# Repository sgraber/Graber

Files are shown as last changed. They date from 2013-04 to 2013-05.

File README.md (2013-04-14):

Graber i3 3D Printer
=================

This is the home of the Graber i3 3D printer: http://www.flickr.com/photos/sbgraber/8536293604/in/photostream/lightbox/

This printer design takes a lot of inspiration from Josef Prusa's awesome 
Prusa i3 printer:

http://reprap.org/wiki/Prusa_i3_Build_Manual#Single_Sheet_Frame_Style

I have decided to give it a name as the design is enough of a departure from its predecessor
that it needs differentiating. I am calling it the "Graber i3" 3D printer. Note on
pronunciation: the 'a' in 'Graber' is long.

What I have done is completely redesign the entire i3 concept to make it laser 
cuttable.  Some designs have taken this idea part-way, making the frame laser
cuttable along with certain motor mounts. With my design, there are no printed
parts, although one could print certain parts if need-be. 

The overall build envelope dimensions remain the same as the Prusa i3, which is
200mm x 200mm x 200mm.

A bill of materials is forthcoming. That said, it is really pretty straight-forward
once you have the laser cut frame put together. I have added some basic labeling
to each part to make assembly easier and here is the part rundown:

* Bottom (A) - 1
* Left Brace (B) - 1
* Right Brace (C) - 1
* Front (D) - 1
* Back (E) - 1
* Frame (F) - 1
* Z-Motor Mount Bottom (G) - 2
* Z-Motor Mount Bottom Brace (H) - 2
* Z-Top (I) - 2
* Z-Smooth Rod Constraint (J) - 2
* Y-Motor Mount (K) - 1
* Y-Idler (L) - 2
* Y-Carriage (M) - 1
* X-Carriage (N) - 2
* Y-Smooth Rod Stop (O) - 4
* Y-Belt Holder (P) - 2
* X-axis smooth rod spacer (Q) - 4
* X-Idler Front (R) - 1
* X-Idler Middle (S) - 1
* X-Idler Back (T) - 1
* X-Idler Top / Bottom (U) - 2
* X-Idler Cap (V) - 1
* X-Motor Front (W) - 1
* X-Motor Middle (X)- 1
* X-Motor Back (Y) - 1
* X-Motor Top / Bottom (Z) - 2
* X-Motor Cap (AA) - 1

NOTE: The long term goal is to make this 3D printer completely laser cuttable, minus the extruder.
Right now the x-motor and x-idler parts remain the only parts untested.  I have just 
committed an x-idler and x-motor that may work. If you choose to build this printer
before these parts are tested, you can use the standard Prusa i3 x-motor and x-idler
parts (even the x-carriage too if you want) and the printer will work fine. 
Expect regular changes to this repository
in the coming weeks, so don't get too comfortable if you download this to cut just
yet.  :)

If you find a bug, I welcome notifications, fixes, and even new contributions.

License
=======

This printer is released under the GNU GENERAL PUBLIC LICENSE v.3, same as its
predecessor.  See LICENSE.md for further details.

Usage
=====

Since this printer is released under the GNU GPL v.3, it is free for anyone to use,
reuse, sell, etc.  One thing I'd ask is if you do sell it that you 
financially contributing back to its continued development and maintenance. 
Contact me at sgraber@gmail.com if willing.

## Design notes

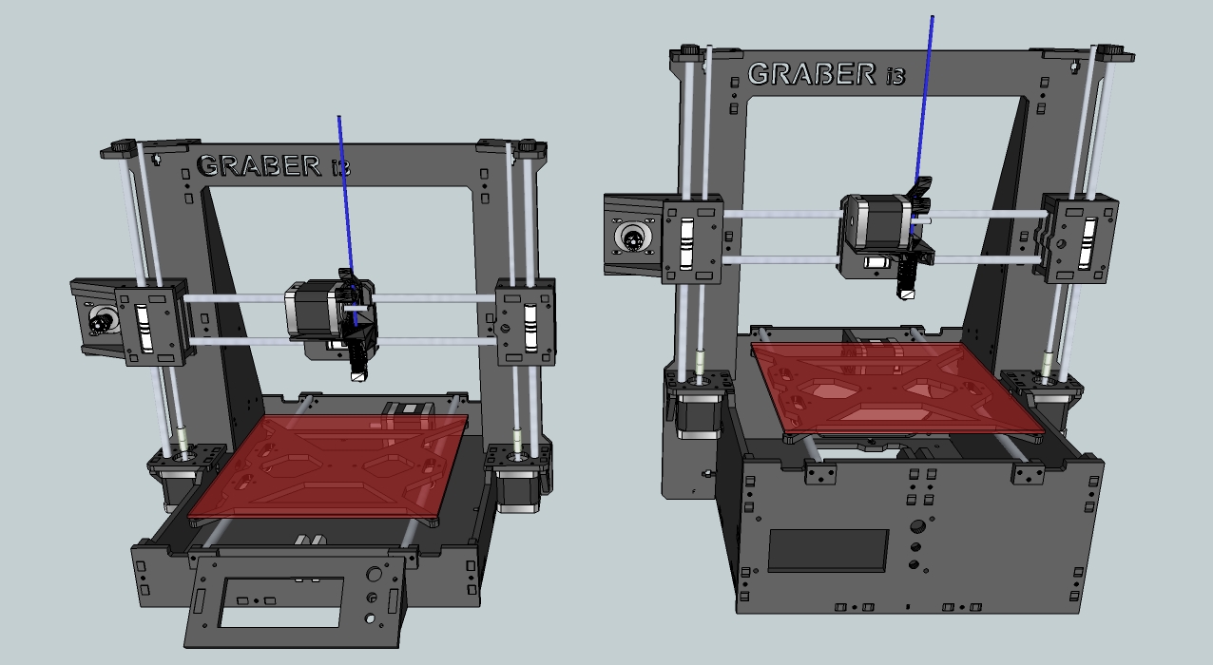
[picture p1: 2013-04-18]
graber-atx-3d2.jpg

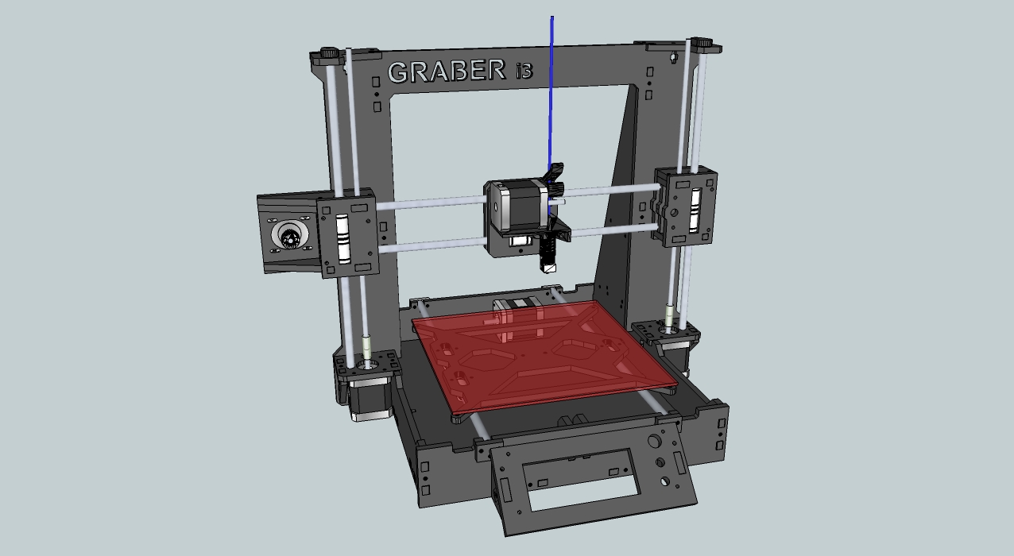
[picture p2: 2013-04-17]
graber-3d.jpg

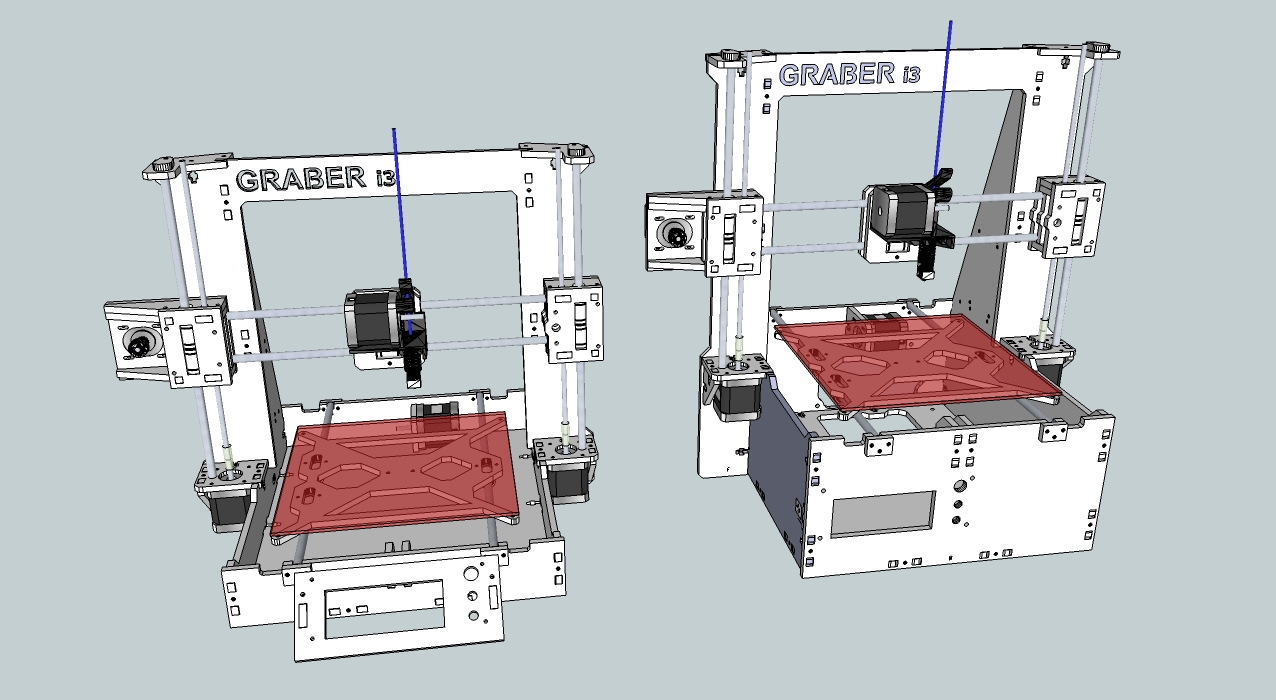
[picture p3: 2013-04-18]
graber-atx-3d.jpg

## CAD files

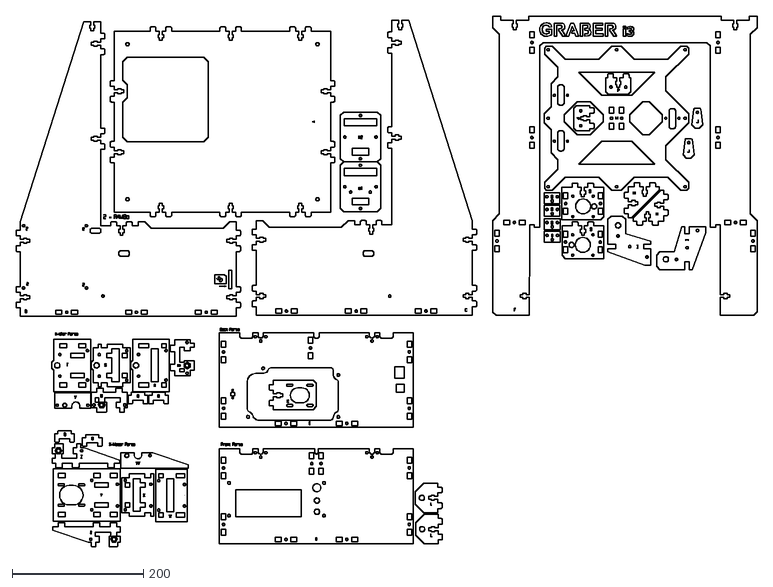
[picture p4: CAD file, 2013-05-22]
graber-atx.dxf
1130.7 x 809.1

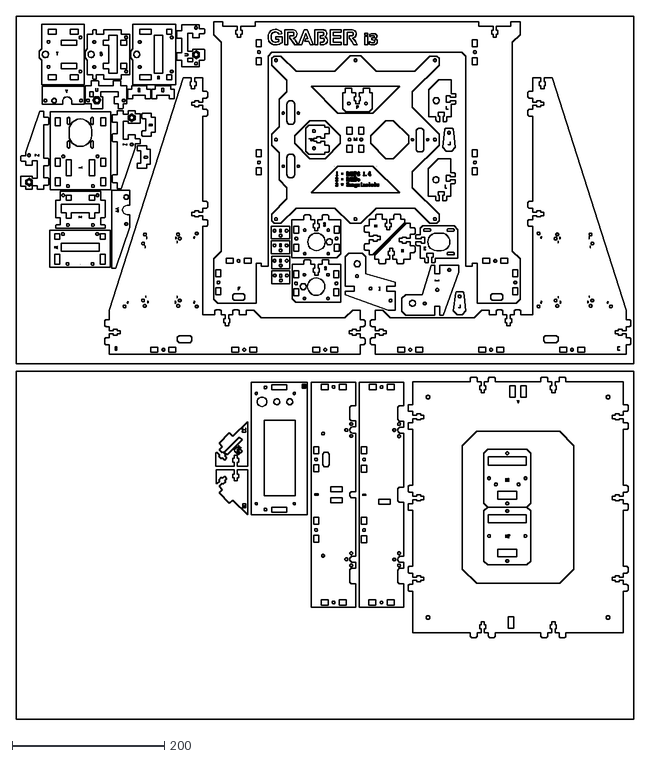
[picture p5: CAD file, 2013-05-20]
graber.dxf
812.8 x 924.7

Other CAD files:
graber-3d.skp
graber-atx.skp
graber.skp

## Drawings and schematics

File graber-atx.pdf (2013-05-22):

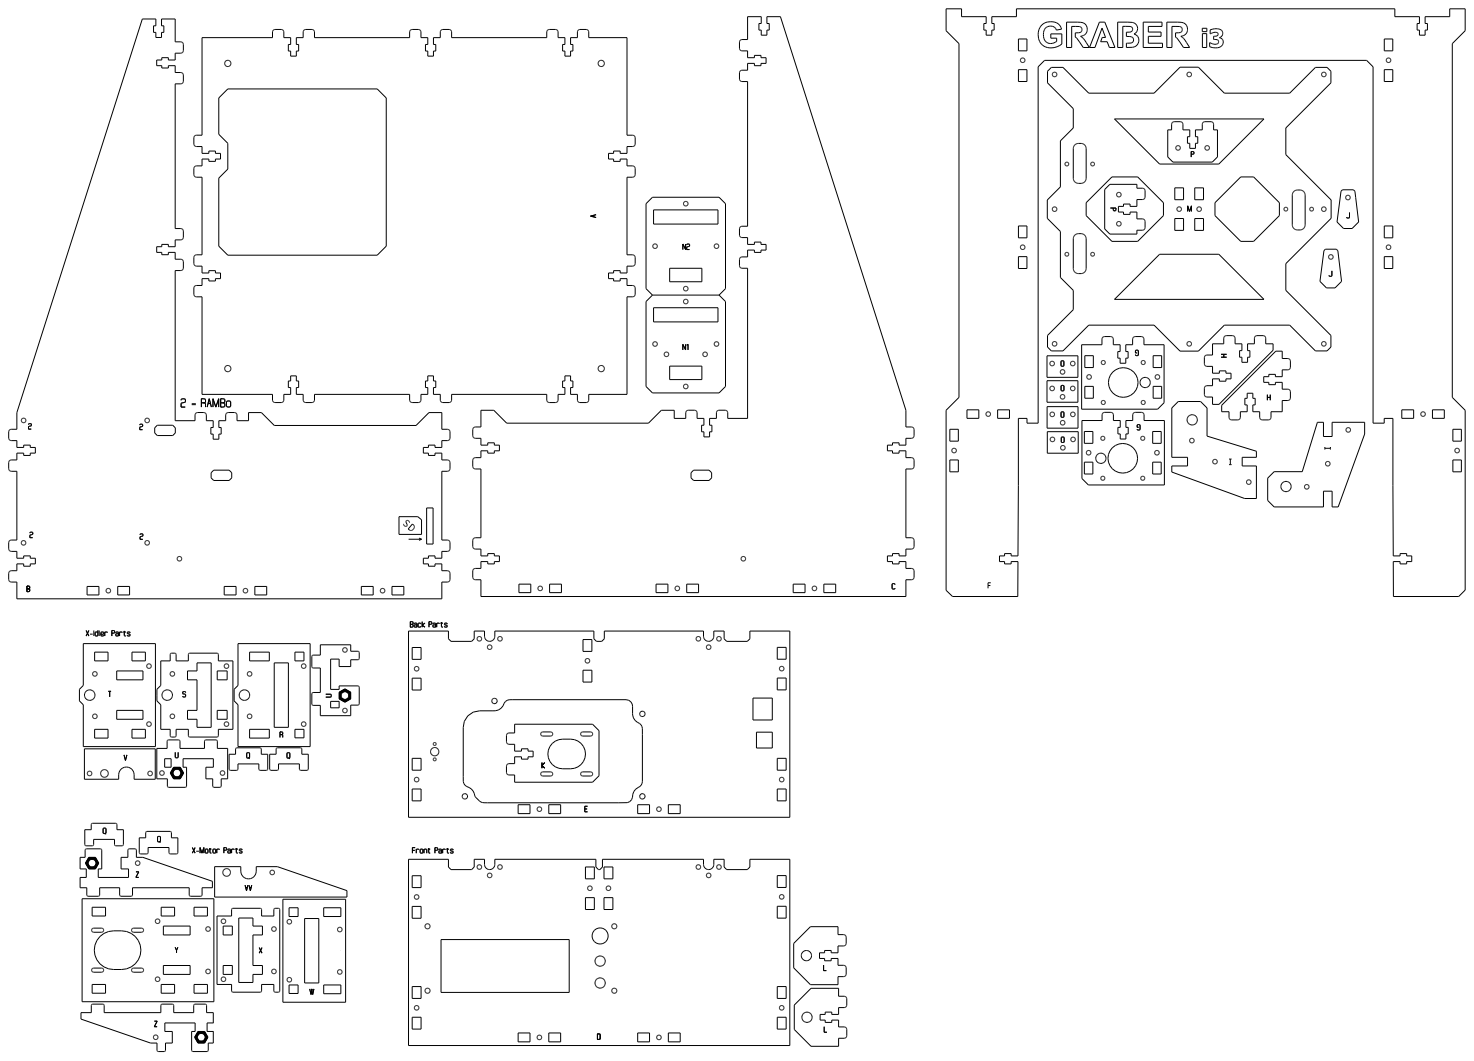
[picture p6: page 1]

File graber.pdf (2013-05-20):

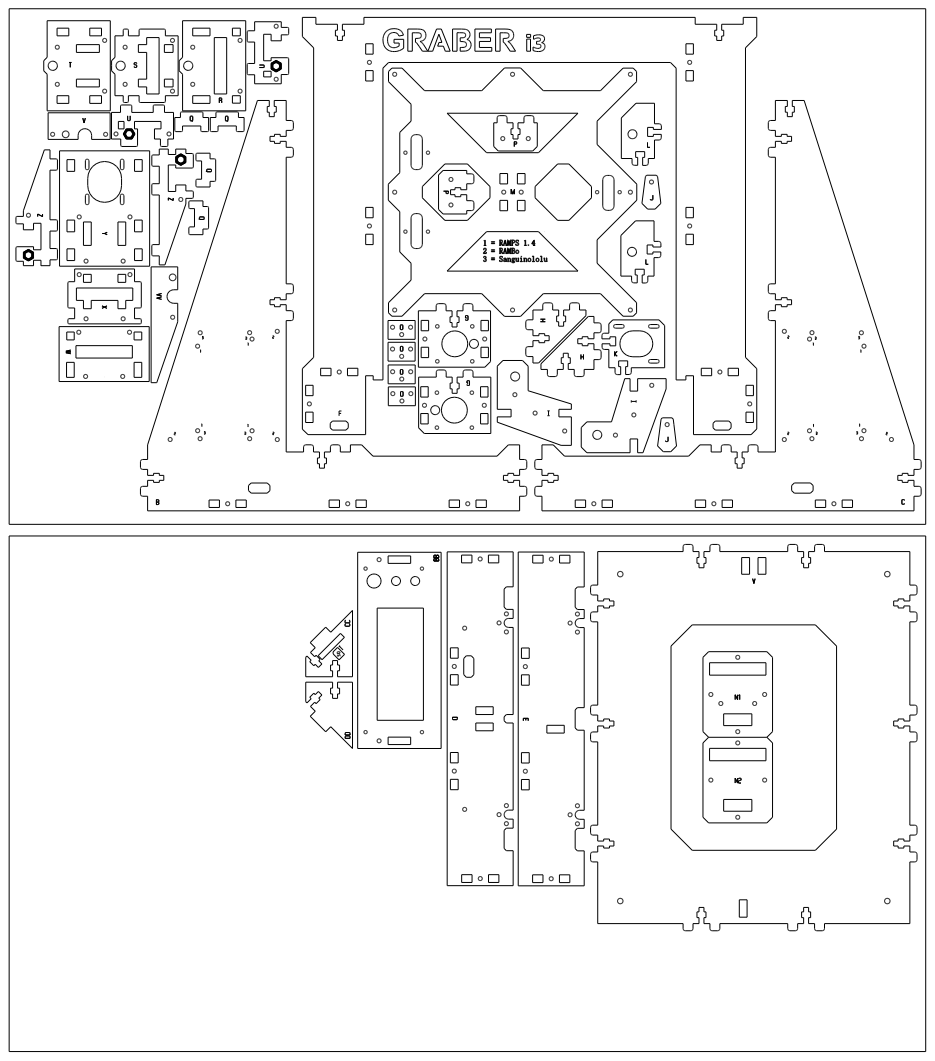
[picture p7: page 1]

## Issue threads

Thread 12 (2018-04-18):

X Motor and Idler

lionbeast, 2018-04-18:
I have laser cut acrylic as per graber-atx.dxf . However, after assembly, there is no space for mounting of lead screw nut and threaded rod in x motor and x idler. Anybody has solution for it?

Thank you

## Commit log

2013-03-06 Updated with license and more printer information.
2013-03-07 initial import
    [graber.dxf, graber.skp]
2013-03-07 3d rendering of the build
    Note: x-axis is still using Prusa i3 x-motor, x-idler, and x-carriage.
    This to be factored out into laser cut wood.
    [graber-3d.skp]
2013-03-07 Added extruder information.
2013-03-08 Fixed incomplete dxf.
    [graber.dxf]
2013-03-09 files for the x-idler and x-motor
    [x-ends-3d.skp, x-ends.dxf, x-ends.skp]
2013-03-09 slight update
    [x-ends.skp]
2013-03-09 Updated model with laser cut x-ends and x-carriage.
    [graber-3d.skp]
2013-03-10 moved M8 smooth rod ziptie holes closer together
    when i assembled the x-idler, the ziptie holes cracked on the piece that
    held the m8 smooth rod. the walls were just too thin. i moved the holes
    closer together so they now do not have a wall.
    [x-ends.skp]
2013-03-21 rounded corners of tab inserts - 2mm radius
    [graber.skp]
2013-03-21 adjusted motor wire holes in bottom of frame
    made them have 45degree angles instead of round for consistency
    [graber.skp]
2013-03-21 added additional renders with various extruder mounts
2013-03-21 adjusted dimensions of flat x-carriage so it uses less wood
    [graber.skp]
2013-03-21 moved x-carriage brace nut traps in 2mm
    keep them from breaking the x-carriage platform when screwed in
    [graber.skp]
2013-03-21 made z-rod stops corners angled
    [graber.skp]
2013-03-21 added bottom cut-out for belt tensioning
    [graber.skp]
2013-03-21 compilation of all graber.skp commits made today
    [graber.dxf]
2013-03-21 made surfaces solid
    [graber.skp]
2013-03-21 adjusted GRABER letters a bit so laser cutting them out won't have thin areas break
    [graber.skp]
2013-03-21 made pieces 'components'
    [graber.skp]
2013-03-22 added 'i3' to frame as a tribute to its ancestory
    [graber.skp]
2013-03-22 added fillet to bottom base hole
    [graber.skp]
2013-03-22 updated with today's commits from graber.skp
    [graber.dxf]
2013-03-22 started adding labeling text to parts
    [graber.skp]
2013-03-22 reverted to four feet on bottom
    bot was just too unstable with three-point leveling
    [graber.skp]
2013-03-22 added part letters - future assembly instructions
    [graber.skp]
2013-03-23 all updates made on 03/22/2013
    [graber.dxf, graber.skp]
2013-04-13 M8 spacers too narrow. opened up to 6.9mm
    [x-idler-1.dxf, x-motor-2.dxf]
2013-04-13 adjusted M5 / #8-32 nut trap diameter
    [x-idler-1.dxf, x-idler-2.dxf, x-motor-2.dxf]
2013-04-13 deleted as redundant w/ x-motor-2.dxf
    [x-motor-1.dxf]
2013-04-13 renamed x-motor-2.dxf to x-motor.dxf
    [x-motor.dxf]
2013-04-13 added latest x-carriage, x-idler, x-motor
2013-04-13 narrowed by 6mm in x
    [x-carriage.dxf]
2013-04-13 moved bearing hole out 4mm as 5/16 nut in path of m5 threaded rod
    [x-idler-1.dxf, x-idler-2.dxf]
2013-04-13 moved outside thru-holes 4mm out. bolts were running thru m5 threaded rod area
    [x-motor.dxf]
2013-04-13 temp file for seemecnc to cut. will go away
    [updated-parts.dxf]
2013-04-14 updated with new x-ends, x-carriage, y-carriage with belt clamp, y-motor tensioning
    [graber.skp]
2013-04-14 added part identification
    [graber.skp]
2013-04-14 updated with latest parts from today's work
    [graber.dxf]
2013-04-15 added lcd parts
    [updated-parts.dxf]
2013-04-15 added lcd add-on to front of printer
2013-04-15 fixed scaling problem
    lcd parts were scaled to 1.18 for some odd reason. resized to
    appropriate size based on reprapdiscount lcd measurements.
    [lcd-addon.dxf, lcd-addon.skp]
2013-04-17 merged reprapdiscount lcd holder into graber.dxf
    [lcd-addon.dxf]
2013-04-17 merged updated-parts.dxf into graber.dxd
    [updated-parts.dxf]
2013-04-17 merged x-idler into graber.dxf
    [x-idler-1.dxf, x-idler-2.dxf]
2013-04-17 merged x-carriage.dxf into graber.dxf
    [x-carriage.dxf]
2013-04-17 merged reprapdiscount lcd into graber.skp
    [lcd-addon.skp]
2013-04-17 removed old ziptie x-ends as obsolete
    [x-ends-3d.skp, x-ends.skp]
2013-04-17 removed ziptie x-ends.dxf as obsolete
    [x-ends.dxf]
2013-04-17 merged x-motor.dxf into graber.dxf
    [x-motor.dxf]
2013-04-17 merged new x-motor, x-idler, and reprapdiscount lcd holder. also widened some tolerances for tabbed assembly.
    [graber.skp]
2013-04-17 new x-motor, x-idler, x-carriage, reprapdiscount lcd holder. also widened numerous tab tolerances.
2013-04-17 merged in x-motor, x-idler, x-carriage, reprapdiscount lcd holder. also widened tolerances on numerous tab holes.
    [graber.dxf]
2013-04-17 updated with latest photo including new x-axis and lcd holder
2013-04-17 added 'i3' to frame top
2013-04-18 version that uses an atx psu under the y-carriage
    [graber-atx.dxf, graber-atx.skp]
2013-04-19 added power supplies
2013-04-19 cleaned up redundant parts
    [graber-atx.skp]
2013-05-18 added groove to front and back parts for 3-point leveling. without groove, y-carriage bolt will run into it.
    [graber.skp]
2013-05-18 added groove to front and back for 3-point leveling on y-carriage
    [graber.dxf]
2013-05-19 moved psu, added rambo holes, wiring holes
    [graber-atx.dxf, graber-atx.skp]
2013-05-20 made bottom hole 30mm wider for easier access to y-carriage
    [graber.dxf, graber.skp]
2013-05-22 adjusted psu hole
    [graber-atx.dxf, graber-atx.skp]
2013-08-04 moved x-carriage extruder mounting holes up 16mm
    with the holes below the gt2 belt connector holes, the extruder mount
    screws were impacting the gt2 belt.
    [graber.skp]
2013-08-04 moved x-carriage mounting holes up 16mm
    extruder mounting holes were impacting the gt2 belt
    [graber-atx.skp]
2013-08-04 updated x-carriage with new hole spacing
